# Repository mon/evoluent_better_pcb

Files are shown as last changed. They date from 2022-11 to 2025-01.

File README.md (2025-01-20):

# Evoluent VM4/VMC/VMD better PCB

Let's face it - the sensor that Evoluent ships with the VerticalMouse series of
mice is at best "OK" and recently, dreadful. While my VM4 and the wireless VMC
was "fine, but office-spec", the VMD jitters, jumps, and cannot keep up with
even moderately fast moves across the mousepad.

So, I created this drop-in replacement PCB to upgrade the sensor to a gaming
grade PMW3360DM, using an atmega32u4 and Arduino.

## Supported models
So far this seems to work with
- VMD
- VMC
- VM4 (large and small)

It *may* work with the VM3.

The current design only supports wired models.

## Installation

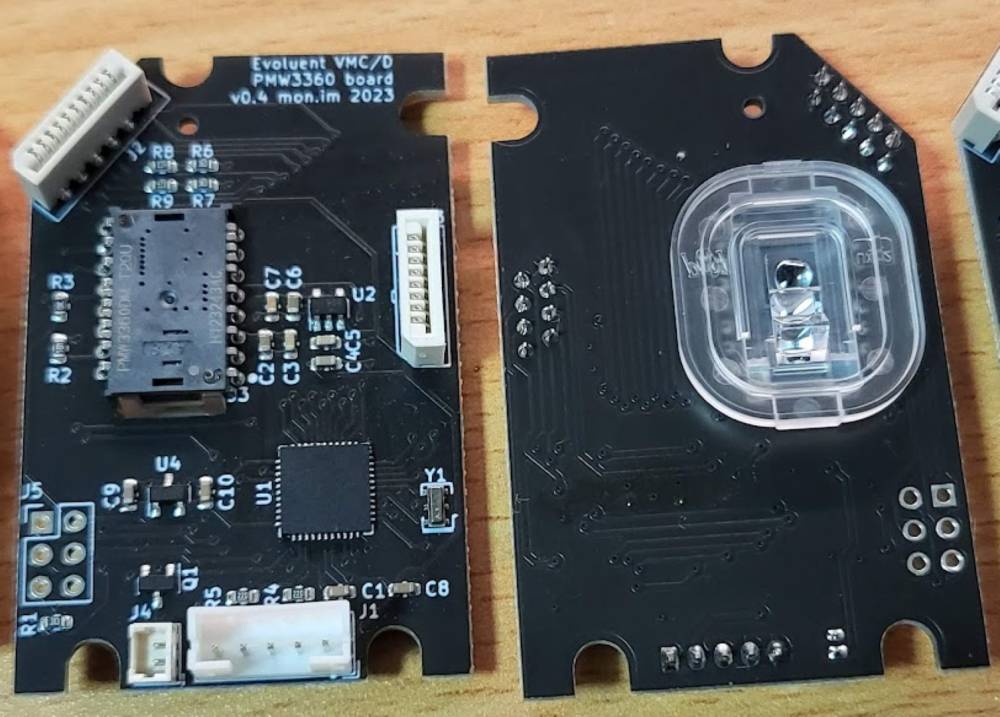
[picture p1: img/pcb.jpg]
PCB image


The PCB has the same shape and pinouts as the stock PCB and is a drop-in replacement.

### Step 1
Remove the bottom off your mouse - this unfortunately requires
taking some of the non-slip feet off. Be as careful as possible to not mangle
the feet when you remove them, or you will significantly affect the smooth feel
of the mouse.

**It is normal for surface smoothness to be poor after you replace the feet.
When I upgraded my VMD, it took 2-3 weeks to return to normal feeling.**

For the **Large** VerticalMouse D, the screws (some of which are Torx security
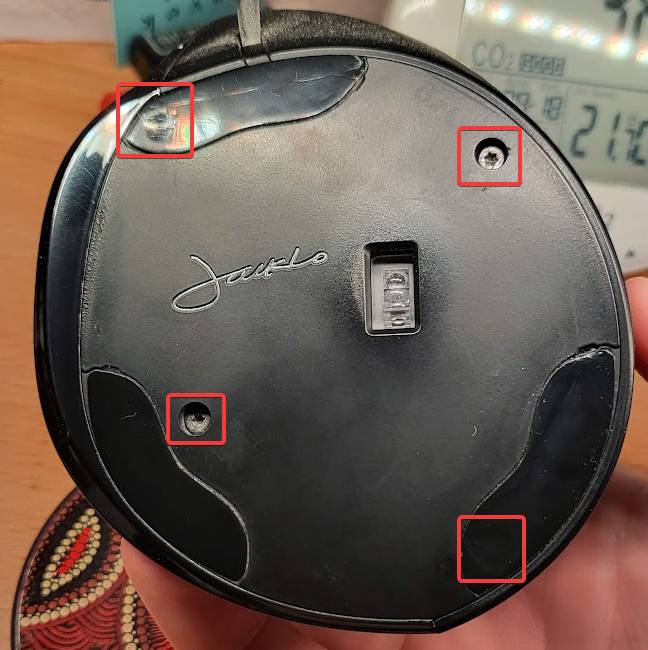
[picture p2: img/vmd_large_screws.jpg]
VMD Right Large
bits) are located here: 

For the VerticalMouse **C**, the screws are located here:  
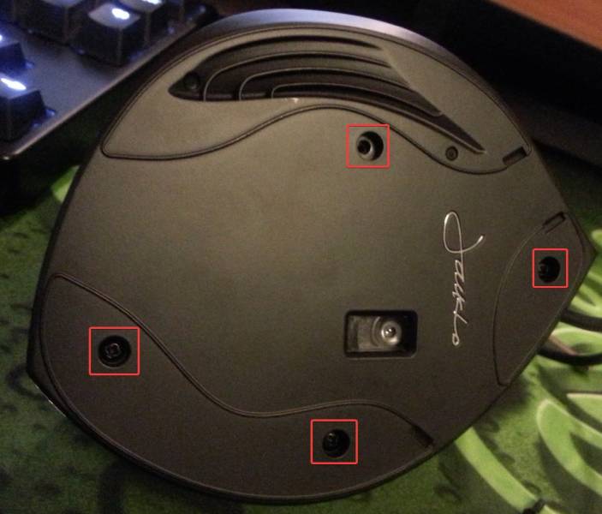
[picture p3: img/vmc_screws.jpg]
VMC


For the **Small** VerticalMouse 4, the screws are located here:  
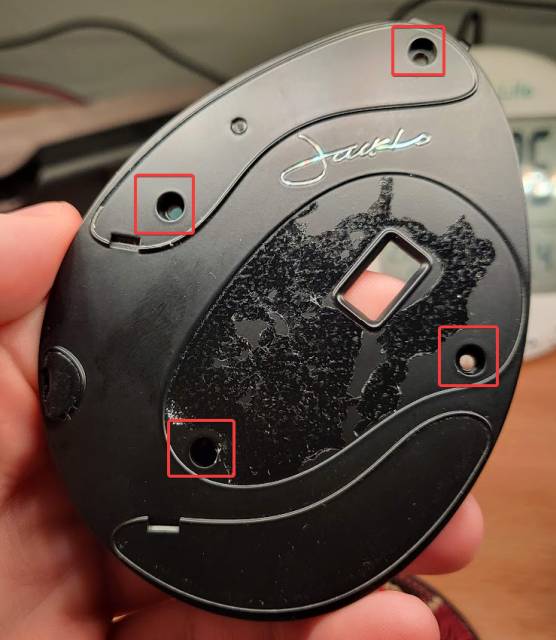
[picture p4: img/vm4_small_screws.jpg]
VM4 Right Small


### Step 2
With the bottom of the mouse removed, unplug all cables from the existing PCB.

The USB cable (the one located at the back of the PCB) can take a fair amount of
force to remove. Ensure you grip at the base of the cable to avoid damage.

The ribbon cables must also be gripped at the base when removing/replacing them,
as they are more fragile than normal cables.

## Step 3
Unscrew and remove the existing PCB. The screws are located here:
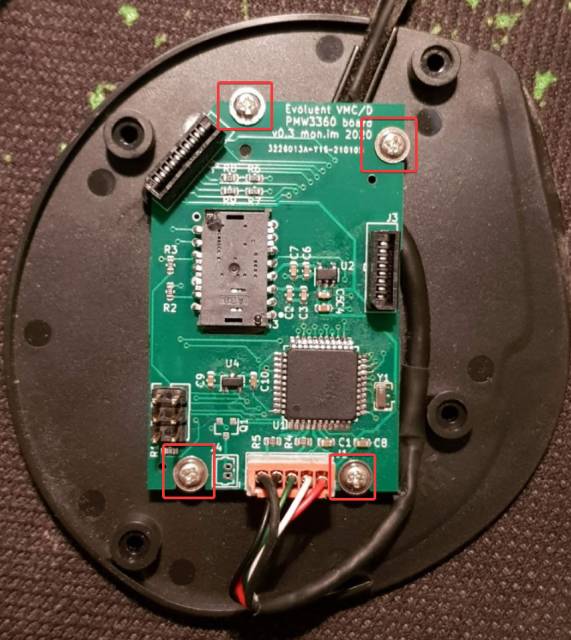
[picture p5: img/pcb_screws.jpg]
VM inner screws


## Step 4
Repeat the disassembly steps in reverse.

## Step 5 (Optional)
For shipped PCBs: If the default firmware is not to your liking, customise it
using the Arduino toolchain. See the "Firmware" section (you can skip the
bootloader as the PCB ships with one).

For PCBs you make yourself: You need to flash the bootloader and firmware, see
the "Firmware" section.

## Firmware

- Using the ICSP pins on the left of the PCB, flash the atmega with the Arduino
  Leonardo bootloader.
- Install the AdvMouse library from the [PMW3360_Arduino
  repository](https://github.com/SunjunKim/PMW3360_Arduino)
- Install the Encoder library under Tools -> Manage Libraries
- The Arduino IDE might not automatically recognise the required files for the project to build. They are:
  - `SROM_0x04_Arduino.ino`
  - `better_evoluent.ino`
  - `usb_rename.cpp`
  - `usb_rename.h`
- Customise your button layout in the struct `button_t buttons[]`.
  - The pin map is:
  - 10: Top mouse button
  - 6: Middle mouse button
  - 4: Lower mouse button
  - 12: Scrollwheel click (for mice that have one)
  - A0: Lower thumb button
  - 2: Upper thumb button
  - (Thumb button pins are reversed on the VMC)
  - 8: Sensitivity/DPI button
- (Optional) Adjust the DPI increments in `dpi_steps[]`
- (Optional) If your buttons are chattery and double-clicking when they
  shouldn't, increase `DEBOUNCE` from 20 to some higher number, such as 50.
- (Optional) Rename the mouse's device name using the `USBRename` line. The
  default is `Evoluent VMD` with manufacturer `mon.im`.
- flash evoluent_better_pcb.ino, selecting Arduino Leonardo as the device type.

I recommend using Device Manager to assign a very high COM port number to the
mouse - that way, you won't accidentally reflash the mouse when working with
other Arduino projects.

The default firmware is basic, but functional. It is based on PMW3360_Arduino's
PMW3360DM-Mouse example and extended for my own uses. It has a serial interface
to configure mouse parameters which is useful when nailing down your preferred
DPI.

The default DPI is the second entry in the list. Clicking the DPI button when
the DPI indicator LEDs are off will show the current DPI. Clicking again within
5 seconds will move the selected DPI through the list. This does not persist
over a power cycle.

## The PCB

It uses the recommended circuit for the PMW3360, with a 1.8v core voltage and
3.3v IO voltage, with the Arduino also running at 3.3v (not 5v).

The PCB is in the `evoluent` subfolder. There are gerbers in `evoluent/production`.

## Assembly/BOM

There is a full BOM csv in `evoluent/production`.

The PMW3360DM (with lens) can be easily bought from aliexpress for about $10
USD.

The FPC connectors for the buttons can be any thru-hole soldered, 1mm pitch
connector. The schematic has the JST 08FMZ-BT/10FMZ-BT, but I ended up buying
something else.

The USB connector is compatible with JST-PH.

The other components are fairly standard, and if the 3v3/1v8 regulators are
unavailable, there will be pin-compatible replacements easily available.

## Support

I use this PCB in my mouse daily. I have been running it for almost 2 years now
without issues, so please get in contact if you are having problems.

You are free to manufacture this PCB and sell it on Tindie etc, just remember to
provide attribution :)

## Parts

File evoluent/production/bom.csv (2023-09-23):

Designator | Footprint | Quantity | Value | LCSC Part #
C1, C10, C9 | 0603 | 3 | 1uF | C15849
C2 | 0603 | 1 | 4.7uF | C19666
C3, C5, C7 | 0603 | 3 | 0.1uF | C14663
C4, C6, C8 | 0603 | 3 | 10uF | C19702
J1 | JST_PH_B5B-PH-K_1x05_P2.00mm_Vertical | 1 | USB_A | C157993
J2 | 10FMZ-BT | 1 | Main switches | C2908574
J3 | 08FMZ-BT | 1 | Thumb switches | C94606
J4 | Molex_PicoBlade_53047-0210_1x02_P1.25mm_Vertical | 1 | Rear lights | C114130
Q1 | SOT-23 | 1 | 2N7002E | C350312
R1, R3, R6, R7 | 0603 | 4 | 10k | C25804
R2 | 0603 | 1 | 39R | C23038
R4, R5 | 0603 | 2 | 22r | C23345
R8, R9 | 0603 | 2 | 4.7k | C23162
U1 | QFN-44-1EP_7x7mm_P0.5mm_EP5.2x5.2mm | 1 | ATmega32U4-M | C112161
U2 | SOT-23-5 | 1 | TLV70019_SOT23-5 | C697975
U4 | SOT-23 | 1 | MCP1700-3302E_SOT23 | C5148692
Y1 | Resonator_SMD_muRata_CSTxExxV-3Pin_3.0x1.1mm | 1 | 16MHz CSTNE16M0V530000R0 | C341521

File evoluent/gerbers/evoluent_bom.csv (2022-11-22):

Source: | evoluent_better_pcb\evoluent\evoluent.sch
Date: | 4/01/2021 8:30:48 PM
Tool: | Eeschema (5.1.5)-3
Generator: | C:\Program Files\KiCad\bin\scripting\plugins/bom_csv_grouped_by_value_with_fp.py
Component Count: | 30
Ref | Qnty | Value | Cmp name | Footprint | Description | Vendor
C1, C9, C10, | 3 | 1uF | C_Small | Capacitor_SMD:C_0603_1608Metric | Unpolarized capacitor, small symbol
C2, | 1 | 4.7uF | C_Small | Capacitor_SMD:C_0603_1608Metric | Unpolarized capacitor, small symbol
C3, C5, C7, | 3 | 0.1uF | C_Small | Capacitor_SMD:C_0603_1608Metric | Unpolarized capacitor, small symbol
C4, C6, C8, | 3 | 10uF | C_Small | Capacitor_SMD:C_0603_1608Metric | Unpolarized capacitor, small symbol
J1, | 1 | USB_A | USB_A | Connector_JST:JST_PH_B5B-PH-K_1x05_P2.00mm_Vertical | USB Type A connector
J2, | 1 | Main switches | Conn_01x10 | Evoluent:10FMZ-BT | Generic connector, single row, 01x10, script generated (kicad-library-utils/schlib/autogen/connector/)
J3, | 1 | Thumb switches | Conn_01x08 | Evoluent:08FMZ-BT | Generic connector, single row, 01x08, script generated (kicad-library-utils/schlib/autogen/connector/)
J4, | 1 | Rear lights | Conn_01x02 | Connector_Molex:Molex_PicoBlade_53047-0210_1x02_P1.25mm_Vertical | Generic connector, single row, 01x02, script generated (kicad-library-utils/schlib/autogen/connector/)
J5, | 1 | Programming header | Conn_02x03_Odd_Even | Connector_PinHeader_2.54mm:PinHeader_2x03_P2.54mm_Vertical | Generic connector, double row, 02x03, odd/even pin numbering scheme (row 1 odd numbers, row 2 even numbers), script generated (kicad-library-utils/schlib/autogen/connector/)
Q1, | 1 | 2N7002E | 2N7002E | Package_TO_SOT_SMD:SOT-23 | 0.24A Id, 60V Vds, N-Channel MOSFET, SOT-23
R1, R3, R6, R7, | 4 | 10k | R_Small | Resistor_SMD:R_0603_1608Metric | Resistor, small symbol
R2, | 1 | 39R | R_Small | Resistor_SMD:R_0603_1608Metric | Resistor, small symbol
R4, R5, | 2 | 22r | R_Small | Resistor_SMD:R_0603_1608Metric | Resistor, small symbol
R8, R9, | 2 | 4.7k | R_Small | Resistor_SMD:R_0603_1608Metric | Resistor, small symbol
U1, | 1 | ATmega32U4-AU | ATmega32U4-AU | Package_QFP:TQFP-44_10x10mm_P0.8mm | 16MHz, 32kB Flash, 2.5kB SRAM, 1kB EEPROM, USB 2.0, TQFP-44
U2, | 1 | TLV70019_SOT23-5 | TLV70019_SOT23-5 | Package_TO_SOT_SMD:SOT-23-5 | 200mA Low Dropout Voltage Regulator, Fixed Output 1.9V, SOT-23-5
U3, | 1 | PMW3360-T2QU | PMW3360-T2QU | Evoluent:PMW3360-T2QU
U4, | 1 | MCP1700-3302E_SOT23 | MCP1700-3302E_SOT23 | Package_TO_SOT_SMD:SOT-23 | 250mA Low Quiscent Current LDO, 3.3V output, SOT-23
Y1, | 1 | 8MHz CSTNE8M00G550000R0 | Resonator_Small | Evoluent:Resonator_SMD_muRata_CSTxExxV-3Pin_3.0x1.1mm | Three pin ceramic resonator, small symbol

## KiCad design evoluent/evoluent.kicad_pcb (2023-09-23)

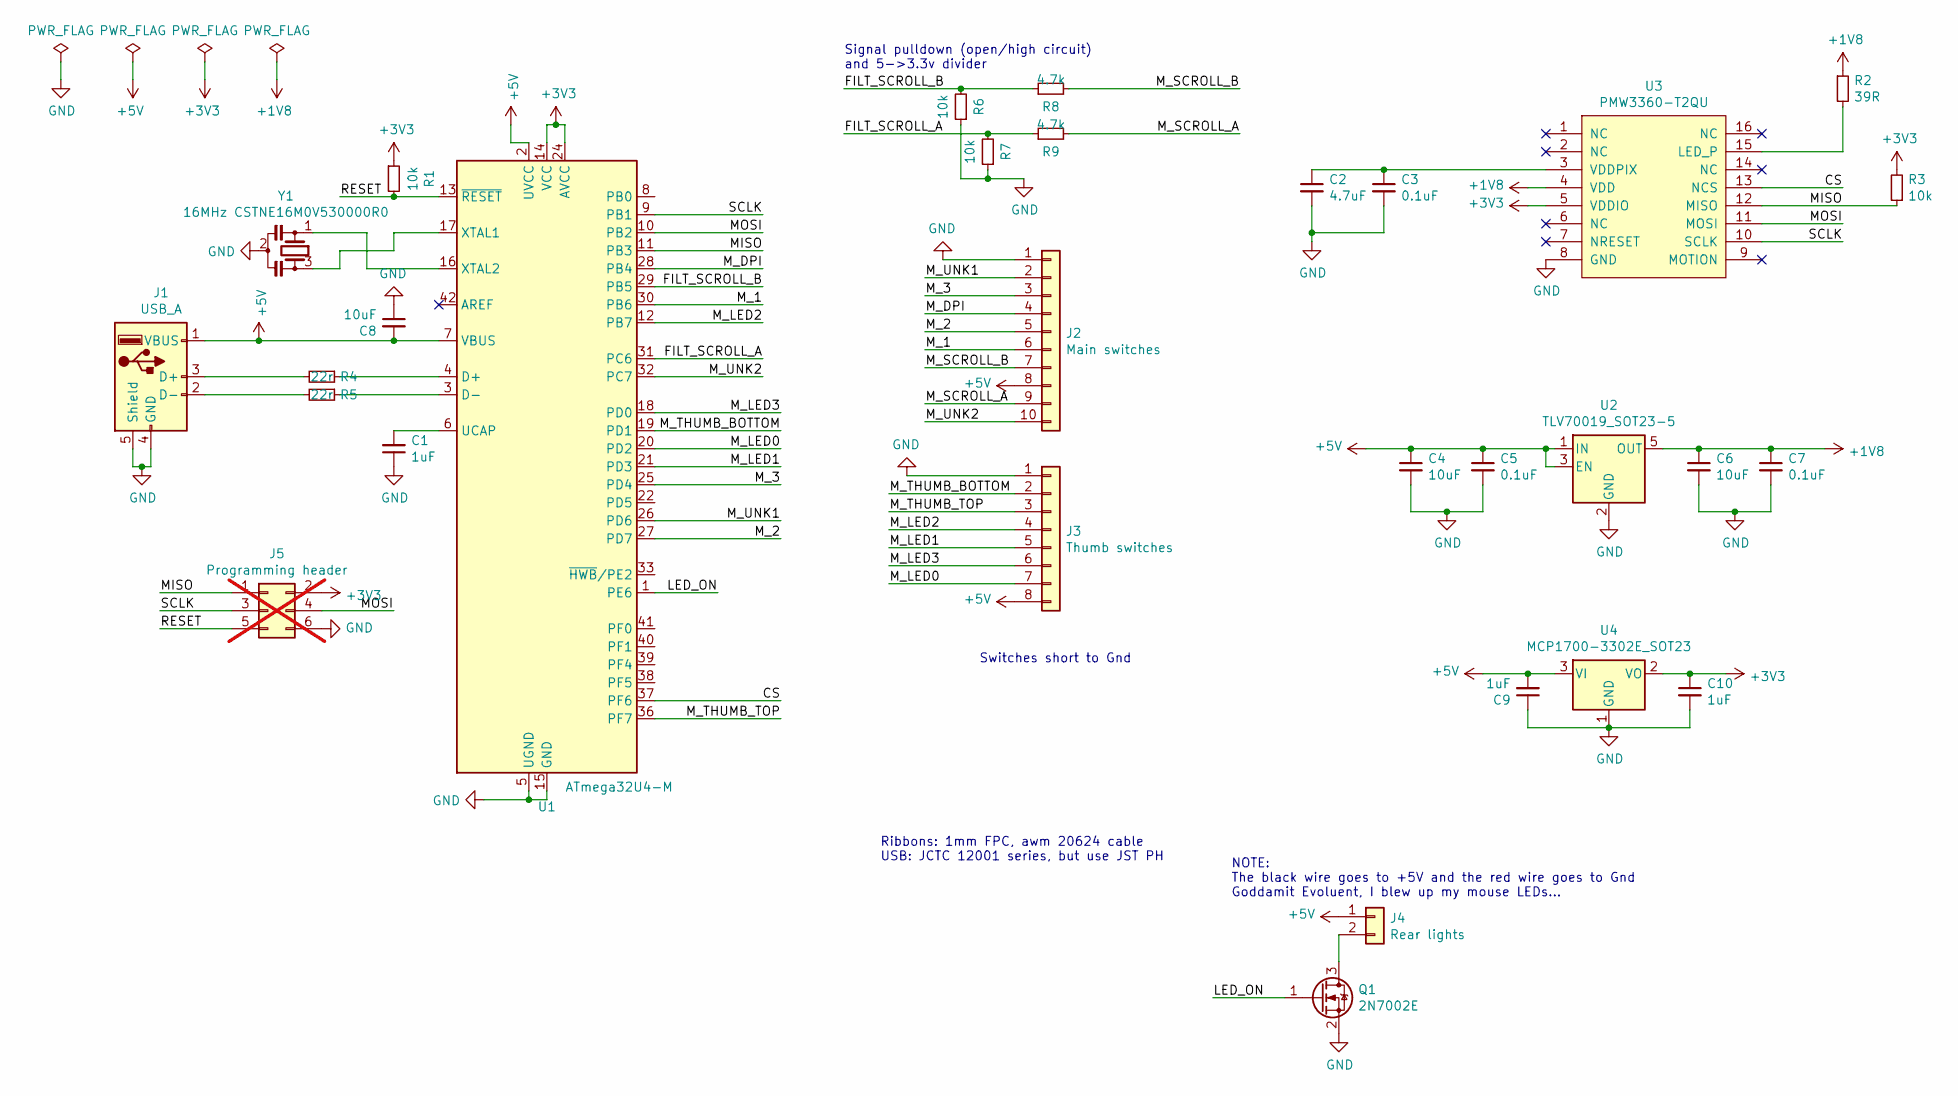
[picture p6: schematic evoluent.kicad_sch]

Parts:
C1, C9, C10: 1uF; C_0603_1608Metric; MPN C15849
C2: 4.7uF; C_0603_1608Metric; MPN C19666
C3, C5, C7: 0.1uF; C_0603_1608Metric; MPN C14663
C4, C6, C8: 10uF; C_0603_1608Metric; MPN C19702
J1: USB_A; JST_PH_B5B-PH-K_1x05_P2.00mm_Vertical; MPN C157993
J2: Main switches; 10FMZ-BT; MPN C2908574
J3: Thumb switches; 08FMZ-BT; MPN C94606
J4: Rear lights; Molex_PicoBlade_53047-0210_1x02_P1.25mm_Vertical; MPN C114130
J5: Programming header; PinHeader_2x03_P2.54mm_Vertical; not fitted
Q1: 2N7002E; SOT-23; MPN C350312
R1, R3, R6, R7: 10k; R_0603_1608Metric; MPN C25804
R2: 39R; R_0603_1608Metric; MPN C23038
R4, R5: 22r; R_0603_1608Metric; MPN C23345
R8, R9: 4.7k; R_0603_1608Metric; MPN C23162
U1: ATmega32U4-M; QFN-44-1EP_7x7mm_P0.5mm_EP5.2x5.2mm; MPN C112161
U2: TLV70019_SOT23-5; SOT-23-5; MPN C697975
U3: PMW3360-T2QU
U4: MCP1700-3302E_SOT23; SOT-23; MPN C5148692
Y1: 16MHz CSTNE16M0V530000R0; Resonator_SMD_muRata_CSTxExxV-3Pin_3.0x1.1mm; MPN C341521

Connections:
+1V8: C6.1, C7.1, R2.1, U2.5 (OUT), U3.4 (VDD)
+3V3: C10.1, J5.2, R1.1, R3.2, U1.14 (VCC), U1.24 (AVCC), U1.34 (VCC), U1.44 (AVCC), U3.5 (VDDIO), U4.2 (VO)
+5V: C4.1, C5.1, C8.2, C9.2, J1.1 (VBUS), J2.8, J3.8, J4.1, U1.2 (UVCC), U1.7 (VBUS), U2.1 (IN), U2.3 (EN), U4.3 (VI)
/CS: U1.37 (PF6), U3.13 (NCS)
/FILT_SCROLL_A: R7.2, R9.1, U1.31 (PC6)
/FILT_SCROLL_B: R6.2, R8.1, U1.29 (PB5)
/LED_ON: Q1.1 (G), U1.1 (PE6)
/MISO: J5.1, R3.1, U1.11 (PB3), U3.12 (MISO)
/MOSI: J5.4, U1.10 (PB2), U3.11 (MOSI)
/M_1: J2.6, U1.30 (PB6)
/M_2: J2.5, U1.27 (PD7)
/M_3: J2.3, U1.25 (PD4)
/M_DPI: J2.4, U1.28 (PB4)
/M_LED0: J3.7, U1.20 (PD2)
/M_LED1: J3.5, U1.21 (PD3)
/M_LED2: J3.4, U1.12 (PB7)
/M_LED3: J3.6, U1.18 (PD0)
/M_SCROLL_A: J2.9, R9.2
/M_SCROLL_B: J2.7, R8.2
/M_THUMB_BOTTOM: J3.2, U1.19 (PD1)
/M_THUMB_TOP: J3.3, U1.36 (PF7)
/M_UNK1: J2.2, U1.26 (PD6)
/M_UNK2: J2.10, U1.32 (PC7)
/RESET: J5.5, R1.2, U1.13 (~RESET)
/SCLK: J5.3, U1.9 (PB1), U3.10 (SCLK)
GND: C1.1, C2.2, C3.2, C4.2, C5.2, C6.2, C7.2, C8.1, C9.1, C10.2, J1.4 (GND), J1.5 (Shield), J2.1, J3.1, J5.6, Q1.2 (S), R6.1, R7.1, U1.5 (UGND), U1.15 (GND), U1.23 (GND), U1.35 (GND), U1.43 (GND), U1.45 (GND), U2.2 (GND), U3.8 (GND), U4.1 (GND), Y1.2
unnamed: J1.3 (D+), R4.2
unnamed: J1.2 (D-), R5.2
unnamed: J4.2, Q1.3 (D)
unnamed: R4.1, U1.4 (D+)
unnamed: R5.1, U1.3 (D-)
unnamed: C1.2, U1.6 (UCAP)
unnamed: U1.17 (XTAL1), Y1.3
unnamed: U1.16 (XTAL2), Y1.1
unnamed: R2.2, U3.15 (LED_P)
unnamed: C2.1, C3.1, U3.3 (VDDPIX)

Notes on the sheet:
Ribbons: 1mm FPC, awm 20624 cable USB: JCTC 12001 series, but use JST PH
Signal pulldown (open/high circuit) and 5->3.3v divider
NOTE: The black wire goes to +5V and the red wire goes to Gnd Goddamit Evoluent, I blew up my mouse LEDs...
Switches short to Gnd

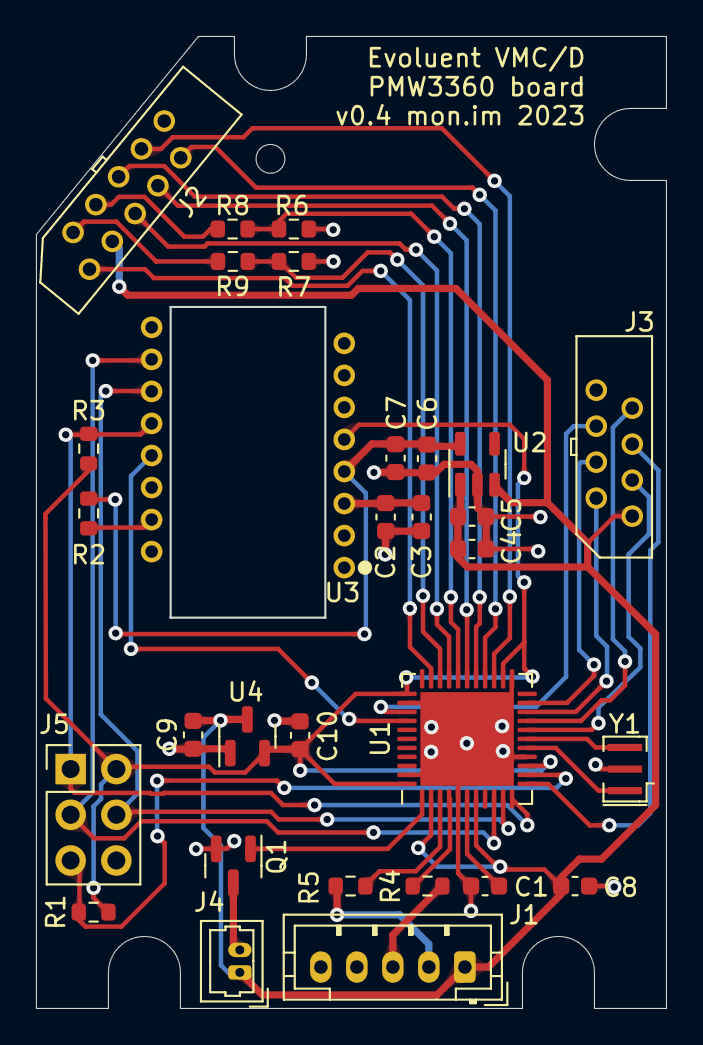
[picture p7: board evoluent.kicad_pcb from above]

Board: 2 copper layers, 35.0 x 54.0 mm, 30 parts (0 on the bottom side), 36 nets.

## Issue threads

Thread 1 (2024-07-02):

Are you still selling custom PCBs?

hkyeollim, 2024-07-02:
Hello, I am using VM4 in South Korea. My wife and I are 3D designers, and we need a vertical mouse with a middle button, and the VM4 is the only mouse that fits our needs. We find the VM4 very useful, but we are experiencing inconvenience due to the poor sensor. I am very glad to have found you through Google. I am using the VM4 in large size, and my wife is using the small size. Are you still selling custom PCBs? We desperately need them. Please reply. Thank you.

mondayoff73@gmail.com

mon, 2024-08-20:
Just to copy what I sent to your email -

> Yes, I am still selling the PCBs, and they fit the VM4 Large. However, I recently found that the Small size won't fit (there is an internal plastic piece that hits a connector).
I have made a redesigned pcb that fits the small size, but it doesn't have firmware yet (it uses a new microprocessor). I'm not sure when it will be done as I'm busy in other areas.

Closed 2024-08-20.

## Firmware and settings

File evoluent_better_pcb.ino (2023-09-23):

// notes
// Board: Arduino Leonardo
// COM port: set to COM222

// Uncomment this line to activate an advanced mouse mode
// Need to install AdvMouse library (copy /library/AdvMouse to the Arduino libraries)
#define ADVANCE_MODE

#include "usb_rename.h"
USBRename dummy = USBRename("Evoluent VMD", "mon.im");

#include <SPI.h>
#include <avr/pgmspace.h>

// PJRC encoder library
#include <Encoder.h>

#ifdef ADVANCE_MODE
  // install manually from PMW3360_Arduino/library/AdvMouse
  #include <AdvMouse.h>
  #define MOUSE_BEGIN       AdvMouse.begin()
  #define MOUSE_PRESS(x)    AdvMouse.press_(x)
  #define MOUSE_RELEASE(x)  AdvMouse.release_(x)
#else
  #include <Mouse.h>
  #define MOUSE_BEGIN       Mouse.begin()
  #define MOUSE_PRESS(x)    Mouse.press(x)
  #define MOUSE_RELEASE(x)  Mouse.release(x)
#endif

// Configurations
// The default CPI value should be in between 100 -- 12000
#define CPI       800
#define DEBOUNCE  30   //unit = ms.

// Registers
#define Product_ID  0x00
#define Revision_ID 0x01
#define Motion  0x02
#define Delta_X_L 0x03
#define Delta_X_H 0x04
#define Delta_Y_L 0x05
#define Delta_Y_H 0x06
#define SQUAL 0x07
#define Raw_Data_Sum  0x08
#define Maximum_Raw_data  0x09
#define Minimum_Raw_data  0x0A
#define Shutter_Lower 0x0B
#define Shutter_Upper 0x0C
#define Control 0x0D
#define Config1 0x0F
#define Config2 0x10
#define Angle_Tune  0x11
#define Frame_Capture 0x12
#define SROM_Enable 0x13
#define Run_Downshift 0x14
#define Rest1_Rate_Lower  0x15
#define Rest1_Rate_Upper  0x16
#define Rest1_Downshift 0x17
#define Rest2_Rate_Lower  0x18
#define Rest2_Rate_Upper  0x19
#define Rest2_Downshift 0x1A
#define Rest3_Rate_Lower  0x1B
#define Rest3_Rate_Upper  0x1C
#define Observation 0x24
#define Data_Out_Lower  0x25
#define Data_Out_Upper  0x26
#define Raw_Data_Dump 0x29
#define SROM_ID 0x2A
#define Min_SQ_Run  0x2B
#define Raw_Data_Threshold  0x2C
#define Config5 0x2F
#define Power_Up_Reset  0x3A
#define Shutdown  0x3B
#define Inverse_Product_ID  0x3F
#define LiftCutoff_Tune3  0x41
#define Angle_Snap  0x42
#define LiftCutoff_Tune1  0x4A
#define Motion_Burst  0x50
#define LiftCutoff_Tune_Timeout 0x58
#define LiftCutoff_Tune_Min_Length  0x5A
#define SROM_Load_Burst 0x62
#define Lift_Config 0x63
#define Raw_Data_Burst  0x64
#define LiftCutoff_Tune2  0x65

const int ncs = A1;  // This is the SPI "slave select" pin that the sensor is hooked up to

unsigned long dpi_led_timeout = 5000;

typedef struct {
  int pin;
  char key;
  bool state;
  uint8_t debounce;
} button_t;

#define DPI_BTN 0x40

button_t buttons[] = {
  {10, MOUSE_LEFT},
  {6,  MOUSE_RIGHT},
  {4,  MOUSE_MIDDLE},
  // scrollwheel click: I don't like it, disable it
  //{12,  MOUSE_MIDDLE},
  // back/forward swapped between VMC and VMD
  {A0, MOUSE_BACK},
  {2,  MOUSE_FORWARD},
  {8,  DPI_BTN},
};

Encoder scrollwheel(5, 9);

int dpi_steps[] = {
  600,
  800,
  1200,
  1600,
};
int dpi_pins[] = {0, 1, 11, 3};
int current_dpi = 0;

#define lengthof(x) (sizeof(x) / sizeof(*(x)))

byte initComplete = 0;
bool inBurst = false;   // in busrt mode
bool reportSQ = false;  // report surface quality
int16_t dx, dy;

unsigned long lastTS;
unsigned long lastButtonCheck = 0;

//Be sure to add the SROM file into this sketch via "Sketch->Add File"
extern const unsigned short firmware_length;
extern const unsigned char firmware_data[];

void setup() {
  Serial.begin(9600);

  pinMode(ncs, OUTPUT);

  for(int i = 0; i < lengthof(buttons); i++) {
    pinMode(buttons[i].pin, INPUT_PULLUP);
  }
  for(int i = 0; i < lengthof(dpi_pins); i++) {
    pinMode(dpi_pins[i], INPUT);
    digitalWrite(dpi_pins[i], LOW);
  }

  // no pull on encoders
  pinMode(5, INPUT);
  pinMode(9, INPUT);

  SPI.begin();
  SPI.setDataMode(SPI_MODE3);
  SPI.setBitOrder(MSBFIRST);
  //SPI.setClockDivider(4);
  Serial.println("ON");

  performStartup();

  // cheeky way to get us to DPI #2
  advance_cpi();

  dx = dy = 0;

  delay(1000);

  //dispRegisters();
  initComplete = 9;

  lastTS = micros();

  MOUSE_BEGIN;
}

void adns_com_begin() {
  digitalWrite(ncs, LOW);
}

void adns_com_end() {
  digitalWrite(ncs, HIGH);
}

byte adns_read_reg(byte reg_addr) {
  adns_com_begin();

  // send adress of the register, with MSBit = 0 to indicate it's a read
  SPI.transfer(reg_addr & 0x7f );
  delayMicroseconds(35); // tSRAD
  // read data
  byte data = SPI.transfer(0);

  delayMicroseconds(1); // tSCLK-NCS for read operation is 120ns
  adns_com_end();
  delayMicroseconds(19); //  tSRW/tSRR (=20us) minus tSCLK-NCS

  return data;
}

void adns_write_reg(byte reg_addr, byte data) {
  adns_com_begin();

  //send adress of the register, with MSBit = 1 to indicate it's a write
  SPI.transfer(reg_addr | 0x80 );
  //sent data
  SPI.transfer(data);

  delayMicroseconds(20); // tSCLK-NCS for write operation
  adns_com_end();
  delayMicroseconds(100); // tSWW/tSWR (=120us) minus tSCLK-NCS. Could be shortened, but is looks like a safe lower bound
}

void adns_upload_firmware() {
  // send the firmware to the chip, cf p.18 of the datasheet
  Serial.println("Uploading firmware...");

  //Write 0 to Rest_En bit of Config2 register to disable Rest mode.
  adns_write_reg(Config2, 0x00);

  // write 0x1d in SROM_enable reg for initializing
  adns_write_reg(SROM_Enable, 0x1d);

  // wait for more than one frame period
  delay(10); // assume that the frame rate is as low as 100fps... even if it should never be that low

  // write 0x18 to SROM_enable to start SROM download
  adns_write_reg(SROM_Enable, 0x18);

  // write the SROM file (=firmware data)
  adns_com_begin();
  SPI.transfer(SROM_Load_Burst | 0x80); // write burst destination adress
  delayMicroseconds(15);

  // send all bytes of the firmware
  unsigned char c;
  for (int i = 0; i < firmware_length; i++) {
    c = (unsigned char)pgm_read_byte(firmware_data + i);
    SPI.transfer(c);
    delayMicroseconds(15);
  }

  //Read the SROM_ID register to verify the ID before any other register reads or writes.
  adns_read_reg(SROM_ID);

  //Write 0x00 (rest disable) to Config2 register for wired mouse or 0x20 for wireless mouse design.
  adns_write_reg(Config2, 0x00);

  adns_com_end();
}

void setCPI(int cpi)
{
  int cpival = constrain((cpi/100)-1, 0, 0x77); // limits to 0--119


  adns_com_begin();
  adns_write_reg(Config1, cpival);
  adns_com_end();

  Serial.print("Got ");
  Serial.println(cpi);
  Serial.print("Set cpi to ");
  Serial.println((cpival + 1)*100);
}

void advance_cpi(void) {
  // first click: show LEDs
  // second click: change
  if(dpi_led_timeout) {
    current_dpi++;
    current_dpi %= 4;
    setCPI(dpi_steps[current_dpi]);
  }

  dpi_led_timeout = 5000;

  // all off
  for(int i = 0; i < lengthof(dpi_pins); i++) {
    pinMode(dpi_pins[i], INPUT);
  }
  // on goes on
  for(int i = 0; i <= current_dpi ; i++) {
    pinMode(dpi_pins[i], OUTPUT);
  }
}

void performStartup(void) {
  // hard reset
  adns_com_end(); // ensure that the serial port is reset
  adns_com_begin(); // ensure that the serial port is reset
  adns_com_end(); // ensure that the serial port is reset

  adns_write_reg(Shutdown, 0xb6); // Shutdown first
  delay(300);

  adns_com_begin(); // drop and raise ncs to reset spi port
  delayMicroseconds(40);
  adns_com_end();
  delayMicroseconds(40);

  adns_write_reg(Power_Up_Reset, 0x5a); // force reset
  delay(50); // wait for it to reboot

  // read registers 0x02 to 0x06 (and discard the data)
  adns_read_reg(Motion);
  adns_read_reg(Delta_X_L);
  adns_read_reg(Delta_X_H);
  adns_read_reg(Delta_Y_L);
  adns_read_reg(Delta_Y_H);
  // upload the firmware
  adns_upload_firmware();
  delay(10);

  setCPI(CPI);
  Serial.println("Optical Chip Initialized");
}

// Button state checkup routine
void check_button_state()
{
  // runs only after initialization
  if(initComplete != 9)
    return;

  unsigned long elapsed = micros() - lastButtonCheck;

  // Update at a period of 1/8 of the DEBOUNCE time
  if(elapsed < (DEBOUNCE * 1000UL / 8))
    return;

  lastButtonCheck = micros();

  // Fast Debounce (works with 0 latency most of the time)
  for(int i = 0; i < lengthof(buttons); i++) {
    int btn_state = !digitalRead(buttons[i].pin);
    if(!buttons[i].debounce && btn_state != buttons[i].state) {
      buttons[i].state = btn_state;
      buttons[i].debounce = DEBOUNCE;

      if((buttons[i].key == DPI_BTN) && btn_state) {
        advance_cpi();
      } else {
        if(btn_state) {
          MOUSE_PRESS(buttons[i].key);
        } else {
          MOUSE_RELEASE(buttons[i].key);
        }
      }
    }
  }
}

// device signature
void dispRegisters(void) {
  int oreg[7] = {
    0x00, 0x3F, 0x2A, 0x02
  };
  char* oregname[] = {
    "Product_ID", "Inverse_Product_ID", "SROM_Version", "Motion"
  };
  byte regres;

  digitalWrite(ncs, LOW);

  int rctr = 0;
  for (rctr = 0; rctr < 4; rctr++) {
    SPI.transfer(oreg[rctr]);
    delay(1);
    Serial.println("---");
    Serial.println(oregname[rctr]);
    Serial.println(oreg[rctr], HEX);
    regres = SPI.transfer(0);
    Serial.println(regres, BIN);
    Serial.println(regres, HEX);
    delay(1);
  }
  digitalWrite(ncs, HIGH);
}

void loop() {
  byte burstBuffer[12];
  unsigned long elapsed = micros() - lastTS;

  check_button_state();
  // keep it updating fast
  scrollwheel.read();

  if(!inBurst)
  {
    adns_write_reg(Motion_Burst, 0x00); // start burst mode
    lastTS = micros();
    inBurst = true;
  }

  if(elapsed > 870)  // polling interval : more than > 0.5 ms.
  {
    adns_com_begin();
    SPI.beginTransaction(SPISettings(4000000, MSBFIRST, SPI_MODE3));

    SPI.transfer(Motion_Burst);
    delayMicroseconds(35); // waits for tSRAD

    SPI.transfer(burstBuffer, 12); // read burst buffer
    delayMicroseconds(1); // tSCLK-NCS for read operation is 120ns

    SPI.endTransaction();
    /*
    BYTE[00] = Motion    = if the 7th bit is 1, a motion is detected.
           ==> 7 bit: MOT (1 when motion is detected)
           ==> 3 bit: 0 when chip is on surface / 1 when off surface
           ] = Observation
    BYTE[02] = Delta_X_L = dx (LSB)
    BYTE[03] = Delta_X_H = dx (MSB)
    BYTE[04] = Delta_Y_L = dy (LSB)
    BYTE[05] = Delta_Y_H = dy (MSB)
    BYTE[06] = SQUAL     = Surface Quality register, max 0x80
                         - Number of features on the surface = SQUAL * 8
    BYTE[07] = Raw_Data_Sum   = It reports the upper byte of an 18‐bit counter which sums all 1296 raw data in the current frame;
                               * Avg value = Raw_Data_Sum * 1024 / 1296
    BYTE[08] = Maximum_Raw_Data  = Max raw data value in current frame, max=127
    BYTE[09] = Minimum_Raw_Data  = Min raw data value in current frame, max=127
    BYTE[10] = Shutter_Upper     = Shutter LSB
    BYTE[11] = Shutter_Lower     = Shutter MSB, Shutter = shutter is adjusted to keep the average raw data values within normal operating ranges
    */

    int motion = (burstBuffer[0] & 0x80) > 0;
    int surface = (burstBuffer[0] & 0x08) > 0;   // 0 if on surface / 1 if off surface

    int xl = burstBuffer[2];
    int xh = burstBuffer[3];
    int yl = burstBuffer[4];
    int yh = burstBuffer[5];

    int squal = burstBuffer[6];

    int x = xh<<8 | xl;
    int y = yh<<8 | yl;

    dx += x;
    dy += y;

    adns_com_end();

    // update only if a movement is detected.

#ifdef ADVANCE_MODE
    // wheel is read at 2x clicks, so halve it
    signed char wheel = scrollwheel.read();
    if(AdvMouse.needSendReport() || motion || wheel)
    {
      AdvMouse.move(dx, dy, wheel/2);

      dx = 0;
      dy = 0;
      scrollwheel.write(wheel % 2);
    }
#else
    if(motion)
    {
      signed char mdx = constrain(dx, -127, 127);
      signed char mdy = constrain(dy, -127, 127);

      Mouse.move(mdx, mdy, 0);

      dx = 0;
      dy = 0;
    }
#endif

    if(reportSQ && !surface)  // print surface quality
    {
      Serial.println(squal);
    }

    for(int i = 0; i < lengthof(buttons); i++) {
      if(buttons[i].debounce) {
        buttons[i].debounce--;
      }
    }

    if(dpi_led_timeout) {
      if(!--dpi_led_timeout) {
        for(int i = 0; i < lengthof(dpi_pins); i++) {
          pinMode(dpi_pins[i], INPUT);
        }
      }
    }

    lastTS = micros();
  }

  // command process routine
  if(Serial.available() > 0)
  {
    char c = Serial.read();
    switch(c)
    {
      case 'Q':   // Toggle reporting surface quality
        reportSQ = !reportSQ;
        break;
      case 'I':   // sensor info (signature)
        inBurst = false;
        dispRegisters();
        break;
      case 'C':   // set CPI
        int newCPI = readNumber();
        setCPI(newCPI);
        break;
    }
  }
}

unsigned long readNumber()
{
  String inString = "";
  for (int i = 0; i < 10; i++)
  {
    while (Serial.available() == 0);
    int inChar = Serial.read();
    if (isDigit(inChar))
    {
      inString += (char)inChar;
    }

    if (inChar == '\n')
    {
      int val = inString.toInt();
      return (unsigned long)val;
    }
  }

  // flush remain strings in serial buffer
  while (Serial.available() > 0)
  {
    Serial.read();
  }
  return 0UL;
}
